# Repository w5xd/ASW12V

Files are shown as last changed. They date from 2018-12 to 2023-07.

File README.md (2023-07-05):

ASW12V

<p>
Remote controllable multi-channel AC/DC switch<br/>
ASW12V: antenna switch for 12V
</p>

My shack has a number of 12VDC controlled circuits for antennas. When
I am sitting at the operating position, they are
 controlled by rotary switches there. 
When connected to the station remotely using WriteLog, I need a way to 
control the switches from the shack PC. This device is a USB controlled
solid state multi-channel AC/DC switch. While its named "12V" the solid state
relay (SSR) outputs can
safely switch up to a maximum of 60V AC or DC, and at up to about 3A. The remainder of
this document uses "12V" to describe the power supply, even though the PCB
is more capable.

In the absence of 
control commands over its USB serial port input,
its output channels follow its input channels. USB power on the 
USB-C plug is required to power the embedded microprocessor for it to
follow its inputs.

<p>This device is controlled by ASCII command strings sent over
its USB serial port. WriteLog is not required to operate it,
but a WriteLog plugin is posted <a href='W5XD-antennas'>here</a> showing 
how to embed
antenna switching commands for this hardware
within WriteLog. The example has on-screen controls corresponding
to the antennas at W5XD. Source code is published.</p>

<p>The power and ground are optically isolated on both input and output side, and separately,
into groups of four channels. Each group of four has its own power and ground terminals.
All the input and output power and ground circuits are optically isolated
from the USB power and ground as used by the Arduino controller on the PCB.</p>
<p>

Revision 8

<p> This documentation is for Revision 8 of the ASW12V. Previous revisions of this design used 
PNP darlington output devices. This SSR design reduces the parts count, and enables both sensing
and controlling AC as well as DC circuits. See the git tag "PCB-REV05" for the documentation for the
version using the STA402 PNP darlington outputs.
</p>
Here is the 24 channel version built with wired connectors:</p>
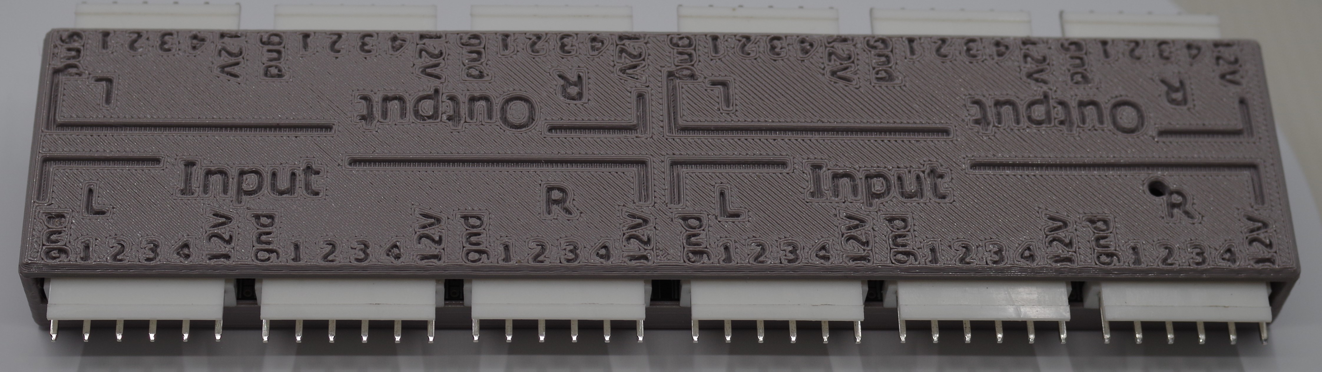
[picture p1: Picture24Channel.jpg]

The longest dimension is just less than 8 in (20cm). The short dimension is about 2.5in (6.2cm). The  
12 channel version is half as wide (4" x 2.5" or 10cm x 6.2cm). 
Here is a populated PCB before connectors are installed. the SMD components are all on the "bottom" of the PCB
and the connectors and QTpy controller (which are through-hole) are installed on the "top".
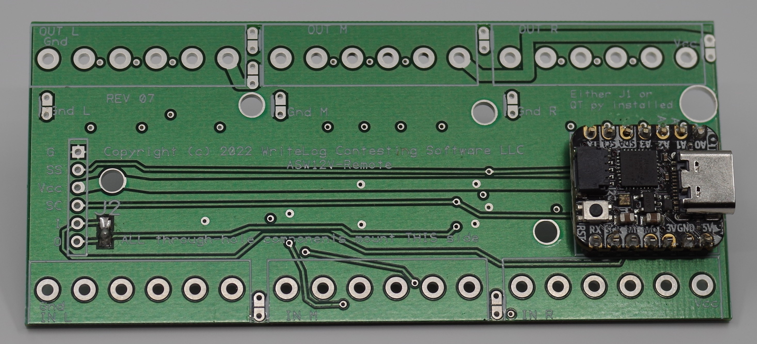
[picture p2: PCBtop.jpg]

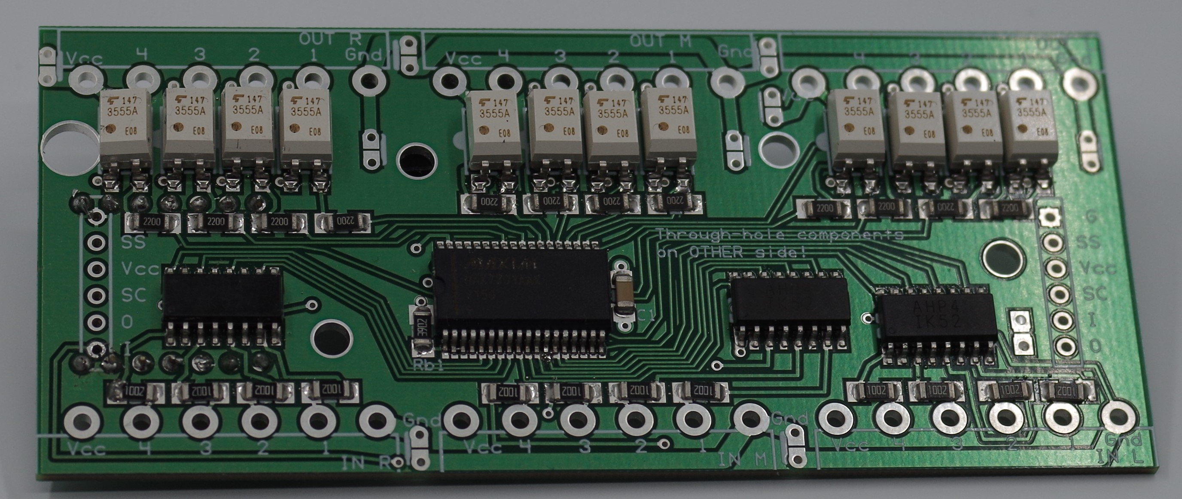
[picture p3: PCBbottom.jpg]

<p>Top and bottom are in quotes because when the SMD components are installed, they must be on  the
top of the PCB in the oven. But when the full device is assembled and in operation, the SMDs are on the bottom.</p>
<br/>
<p>Power and Ground</p>

<p>The PCB layout has three sections each with four input/output channels and with grounds and
VCC isolated to that section. In the photo above, all the G and 12V connections are, without installing any jumpers,
 isolated from each other. Solder jumpers on the PCB enable interconnects among them. See below.
 The power and ground circuit is this:
<a href='ASW12V-circuit3.pdf'>ASW12V-circuit3.pdf</a>. 
Many different power supply options are supported by jumper options on the PCB for exactly what Ground and 
VCC connections are interconnected on
the PCB. One thing that is not optional: fuse at about 3A or otherwise current limit the connection from the
 power supply to the Vcc terminal on the ASW12V. The ASW12V PCB has components too dense to service. Plan on
 replacing it if it is damaged by over current.
 
You can successfully use this device with NONE of these jumpers in place. But consider how you want to use it.
In my own case, the same 12VDC supply powers all my antenna relays, so I can safely tie all the Gnd and VCC
terminals together. Your shack may differ.

The PCB has jumpers that can internally connect:</p>
<ol>
<li>the VCC pin to the VCC on the adjacent section.
<li>the OUTPUT GND pin to the OUTPUT Gnd pin of the adjacent section.
<li>the INPUT Gnd pin to the OUTPUT Gnd pin of the section.
<li>the INPUT GND pin to the INPUT Gnd pin of the adjacent section.
 </ol>
 The positions of the jumpers are hand-outlined on this <a href='ASW12V-bottom.pdf'>bottom view of the PCB silkscreen</a>. 
 The jumpers are most easily installed (and removed) on the bottom side of the PCB. The jumpers corresponding to (1) and (2) are at the top of the picture, 
 the ones for (4), the INPUT to INPUT, are at the bottom and the ones for (3) are between.
 
 The circuit board traces are wide enough
 to suppoart a total of 3A to the VCC and GND connectors on each terminal block.
 
Construction

<p>A parts list, construction details, and a PCB layout are published <a href='construction.md'>here</a>.</p> 

Inductive Loads

The solid state relays do not have built-in protection from any inductive voltage spike that happens as
an inductive load is turned off. The PCB has 12 positions for diodes to be installed, labeled D11 up through D44.
Installing these diodes is optional. They are not needed for non inductive loads, nor for inductive loads that have
their own flyback diodes installed (e.g. the Array Solutions 6-Pak in my shack.)

Controlling the ASW12V

A USB connection to the USB-C connector is required for operation of the microcontroller. Without USB power, all outputs are
off. The sketch on the Arduino powers up
in a pass through mode. That is, the firmware transfers the INPUT
side as a pass through to the OUTPUT&mdash;a signal on an INPUT pin results in Vcc applied to corresponding OUTPUT pin on
the opposite side of the box.
<p>When plugged in to a computer, the drivers for its USB port automatically are installed (on most
 operating systems) and create a virtual serial port. An example program to write useful serial commands is published <a href='W5XD-antennas'>here on github</a>. The example
is specific to the antennas to be controlled at W5XD. It doesn't put much on the screen. as not much is required at W5XD.</p>
<p>Control the beverages, one to the RX antenna on each of two radios:</p>
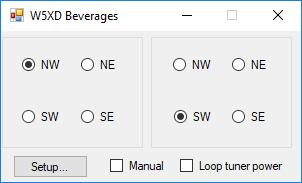
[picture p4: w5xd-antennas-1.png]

<p>Control the main transmit antenna, one of 6 to each of two radios:</p>

<p>All the buttons on the two windows above can be programmed as keyboard shortcuts in WriteLog.</p>
Enclosures

<p>This repository publishes a design for an enclosure a 24 channel device (with 2 PCBs) with connectors installed on the PCB.
 The 3D designs were done with <a href='solidedge.com'>Solid Edge</a>. 
The PCB hole pattern accommodates either the screw terminals or the connector. The
Solid Edge models are in the CAD folder. The 3D printable parts are published in the <a href="STL/">STL</a> directory. Unfamiliar with 3D design 
and printing? Don't be bashful about clicking the <a href="STL/">STL</a> link and the enclosure models. </p>

I use a <a href='http://prusa3d.com'>prusa3d</a> printer.

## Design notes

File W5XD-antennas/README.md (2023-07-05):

Antenna switch control for station W5XD

This is a .NET application for controlling the antenna switching at W5XD.
It serves as an example of both how an ASW12V might be used,
and how to split a WriteLog keyboard shortcut processor between control-site
and remote-site.

My station has these items to control:
<ul>
<li>Four beverage antennas (receive only) that each can be switched into the RX antenna port of either of two rigs. The
 rigs are called "primary" and "secondary" because my relay circuit
only routes each beverage to one rig at a time, and the primary radio always wins when both controls are switched 
    to the same direction.</li>
<li>A 12VDC supply for remote tuner (MFJ-998RT). That tuner can be commanded to find a better match by cycling its power off then back on.</li>
<li>Antennas switched with an Array Solutions <a href='https://www.arraysolutions.com/antennas-switching/sixpak-so'>SixPak</a></li>
</ul>

Also at W5XD, the operator tends to run WriteLog for his logging software (funny thing
about that.) Beverages really need to be switched from within the contest logging program
with just a keystroke. This is important when trying to pull a weak signal out of the noise at the same time as typing the CALL.
(For this particular function, its not an effective computer/user interface to
change the keyboard focus outside the logging program and then back.)

That beverage-switching problem is why this .NET application is structured to build both 
a .exe (to run standalone) and a .NET assembly.
When you open this Visual Studio solution, W5XD-antennas.sln, you build both. If you run the exe standalone 
you get control over the ASW12V,
but not from within WriteLog. Instructions for using the assembly within WriteLog are below. 

Here is a picture of how the ASW12V gets wired into the control circuits for the SixPak. (The
beverage controls are not shown here. They are similar with the exception of having only four positions
on the control switches.)
Before installing the ASW12V, the SixPak controls are wired this way:
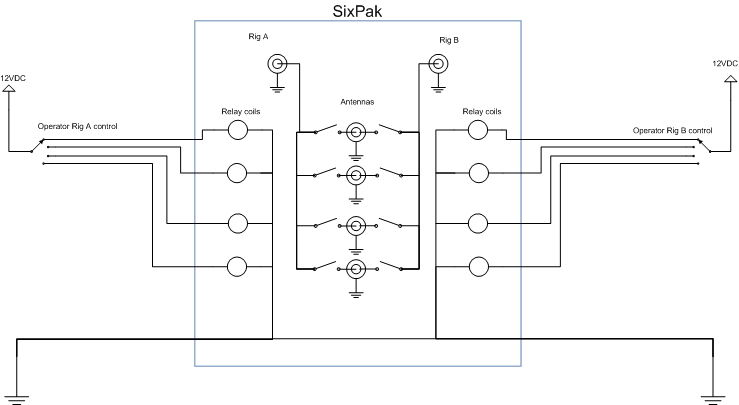
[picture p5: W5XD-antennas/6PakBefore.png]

(SixPak internal circuit here is only representative. I omit its safety latches, and 
show only four of the six channels.) Just cut the control cable between the operator position and the relay box and wire in the ASW12V:
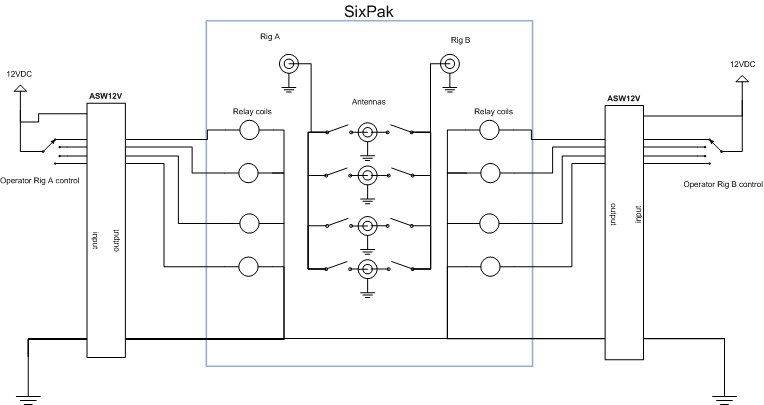
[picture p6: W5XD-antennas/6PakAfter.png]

For simplicity in the diagram I show the control cables split at
two ASW12V boxes. But in my shack, both control cables are routed through
just one ASW12V. And its the 24 channel version. The beverage
and tuner power switching are all routed to the same terminal blocks
and all controlled using one virtual COM port.
<br/>
<p>The diagram shows that power and ground are connected on the INPUT side of the ASW12V.
If your load exceeds about 1A (of the 3A maximum rating) then
wire the heavier power and ground leads to the power source on the OUTPUT side of the
ASW12V to avoid overloading the internal (and smaller) INPUT to OUTPUT power and ground jumper traces.</p>

To use within WriteLog, place a copy of the W5XD_antennas_shortcuts.dll in WriteLog's Program directory,
and make a new entry in WriteLog.ini. WriteLog can then access the beverage switching from
keyboard shortcuts. The INI entry looks like this:
<pre><code>
[ExternalShortcuts]
W5XD_antennas_shortcuts.WriteLogKeyProcessor=W5XD_antennas_shortcuts</code>
</pre>
WriteLog doesn't need the .exe file. Only the .dll need be installed in WriteLog's Program folder. To get the antenna controller on the screen assign any (or all) of its four shortcuts to keyboard keys, then invoke one.

<h3>WriteLog Remote Control</h3>
WriteLog as of its version 12.36 supports keyboard shortcut processing split across
the control-site to the remote-site. This project shows how to accomplish that
in its .NET source code. The Writelog.ini setting at the remote site is as above, but at the control site,
you need this entry instead:
<br/><code>W5XD_antennas_shortcuts.WriteLogKeyProcessorControlSite=W5XD_antennas_shortcuts</code>

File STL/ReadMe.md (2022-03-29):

STL model for 24 channel enclosure with the plug-in connectors installed (as opposed to the screw terminal connectors)

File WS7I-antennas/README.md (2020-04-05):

Antenna switch control for station WS7I

This is a .NET application for controlling the antenna switching at WS7I.
It serves as an example of both how an ASW12V might be used,
and how to split a WriteLog keyboard shortcut processor between control-site
and remote-site.

The station has one antenna switch that attaches one of these to the rig
<ul>
<li>TH7
<li>7 MHz
<li>3.5 MHz
<li>2.0 MHz
</ul>

To use within WriteLog, place a copy of the WS7I_antennas_shortcuts.dll in WriteLog's Program directory,
and make a new entry in WriteLog.ini. WriteLog can then access the beverage switching from
keyboard shortcuts. The INI entry looks like this:
<pre><code>
[ExternalShortcuts]
WS7I_antennas_shortcuts.WriteLogKeyProcessor=WS7I_antennas_shortcuts</code>
</pre>
WriteLog doesn't need the .exe file. Only the .dll need be installed in WriteLog's Program folder. To get the antenna controller on the screen assign any (or all) of its four shortcuts to keyboard keys, then invoke one.

<h3>WriteLog Remote Control</h3>
WriteLog as of its version 12.36 supports keyboard shortcut processing split across
the control-site to the remote-site. This project shows how to accomplish that
in its .NET source code. The Writelog.ini setting at the remote site is as above, but at the control site,
you need this entry instead:
<br/><code>WS7I_antennas_shortcuts.WriteLogKeyProcessorControlSite=WS7I_antennas_shortcuts</code>

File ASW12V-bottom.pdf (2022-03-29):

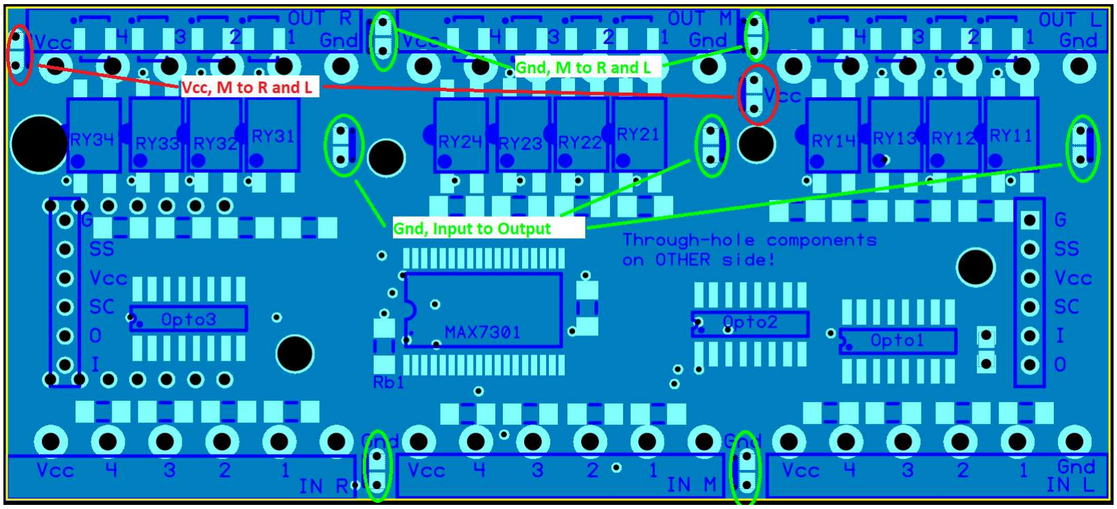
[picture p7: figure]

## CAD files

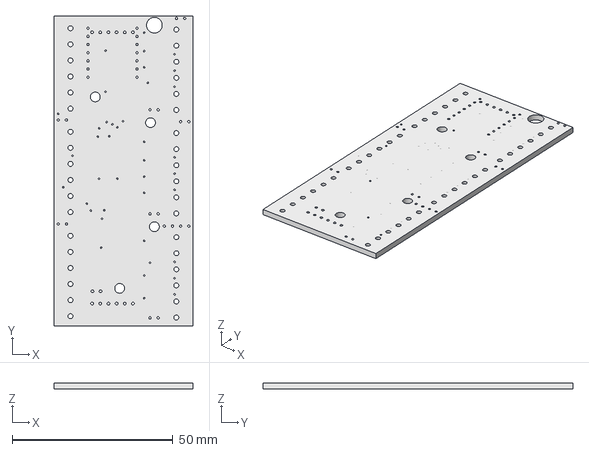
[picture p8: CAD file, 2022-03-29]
SolidEdge/pcb-qtpy.step
43.2 x 96.5 x 1.78 mm

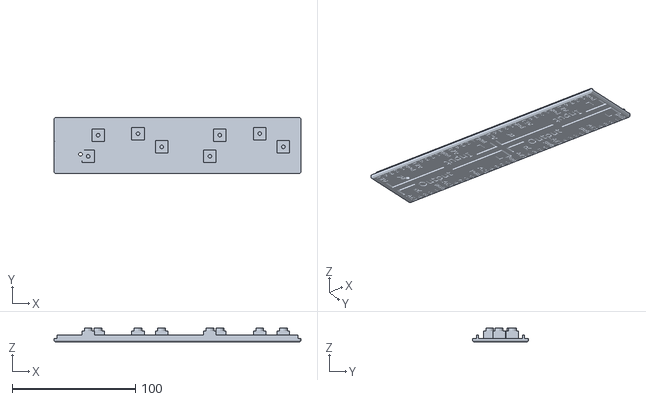
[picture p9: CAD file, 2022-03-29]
SolidEdge/QTpy/enc24-top.stl
200.4 x 45.8 x 11.1

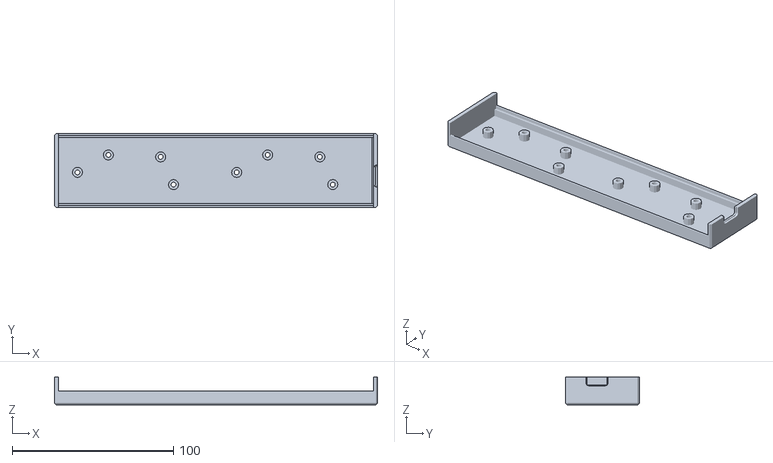
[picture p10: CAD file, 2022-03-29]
STL/enc24-bottom.stl
200.4 x 45.8 x 17.2

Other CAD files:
STL/enc24-top.stl

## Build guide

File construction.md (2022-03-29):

ASW12V Construction
<h3>Parts lists</h3>
The parts of a 12-channel, single-PCB device can all&mdash;except the PCB and enclosure&mdash; be obtained at digikey:
<a href="partslist.pdf">partslist.pdf</a>.
Or here is a link to the equivalent digikey shared shopping cart:
<a target="_blank" href="https://www.digikey.com/short/tr1t8r3d">https://www.digikey.com/short/tr1t8r3d</a>.

<p>The digikey references above do <b>not</b> include the necessary input/output screw terminals or connectors. The PCB design accommodates 
either of these connector configurations:</p>
<ul>
<li><a target="_blank" href='https://www.digikey.com/short/z8zprc'>Phoenix Contact 1935200 </a>. (screw terminals)<br/>
OR
<li><a target="_blank" href='https://www.digikey.com/short/z8zprj'>TE Connectivity AMP Connectors part 1744048-6</a>. (male pins on plug.)
This plug mates with these parts:
<ul>
<li><a target="_blank" href='https://www.digikey.com/short/z8zprb'>mating housing</a>
<li><a target="_blank" href='https://www.digikey.com/short/z8zprd'>crimp pins</a>
</ul>
</ul>

<p>The parts lists above also do <b>not</b> include the board-to-board connectors you'll need to 
interconnect the two PCBs if you build the 24 channel version:</p>
<ul>
<li><a target="_blank" href='https://www.digikey.com/short/z8prdt'>Right angle connection header, male</a>. </li>
<li><a target="_blank" href='https://www.digikey.com/short/zp42fr'>Right angle connection header, female</a>. </li>
<li>Double all the quantities in the parts list above.</li>
</ul>

If you're going to build several of these in a batch, here is a handy <a href='https://www.digikey.com/short/zp4253'>part</a>. 
It can be used with a jig (which you'll have to design and build) to jumper any Arduino (of any size)
 to test a partially 
populated PCB. See the testing instructions <a href='#TestJig'>below</a>.

The printed circuit board is a four layer design. You must have them built.
It was designed with <a target="_blank" href="http://expresspcb.com">expresspcb</a> and the
file is ASW12V.rrb. 
<ol>
<li>This repository maintains only the most recent PCB revision's documentation in the master branch. Look for tags to find documentation of older revisions.</li>
<li>Revision 8 uses Solid State Relay outputs, the QTpy Arduino device, and the MAX7301 i/o extender. Its the
smallest form factor of all the revisions.</li>
<li>Revision 6 accommodates the pinout of the more readily available STA402 10-pin SIP PNP darlington, and 
adds 2 Amp SMD size <code>1206</code> flywheel diodes to accommodate inductive loads (which includes, for example, a relay coil!) The 
SMA4021 part for earlier PCBs has built-in flywheel diodes.
<li>Revision 5 is identical to Revision 6, but its gerber file.top has been hand edited to remove a stray trace.
<li>Revision 4 adds pads for SMD <code>1206</code> size resistors while the through-hole positions remain an option. 
	Install one or the other. </li>
	<li>Revision 4 and earlier accommodate the SMA4021 12-pin SIP Darlington PNP with built-in flywheel diodes. </li>
<li>Revision 3 and later of the PCB is limited to 3A among its outputs.
Earlier revisions have lower current limits. Revision 3 and later of the PCB accommodates either of the above interconnects. </li>
</ol>
 
Program the Arduino QTpy with the sketch published in <a href="sketch//ASW12V">sketch/ASW12V/</a>. 

<h3>Construction Recommendations</h3>
    
Install <i>only</i> the SMD parts and stop to test:
<ol type="a">
    <li>You will need reflow solder oven.</li>
   <li>Place and bake all the SMD parts.</li>
</ol>
There is more than one way to test for solder bridges and/or pins that missed soldering. Choose a way to test
and verify the SMD components are working before soldering the Input and Output connectors. Its a lot harder to work
with the board with those connectors in place.

Possible hardware configurations for testing

All the jumpers on the PCB have through holes for a wire jumper, and also have solder pads on both the top
and the bottom so you can bridge a blob of solder across the jumper. This pad configuration is on all of them: 
the I to O jumper at J2, the GND
jumpers and both of the Vcc jumpers.
<ol>
<li>Install the QTpy on the PCB (<b>notice it goes on the opposite side of the board from the SMD parts!</b>)<br/>
OR</li>

<li>Install male headers on your QTpy and then use
<ol type="a">
    <li> 6 jumpers to temporarily wire it to the PCB. I used these jumpers from 
<a href='http://www.sparkfun.com/products/10898'>sparkfun</a>.</li>
    <li>If this test is for a board that will have the QTpy controller, then 
    you may install a sacrificial header now at J1.
A vertical header (straight pins) will work, but if you don't know where you're going to
    install this board, then install a right angle header as if it will not be the first board (i.e. one without
a QT py). If it ever is to become the first board,
    you'll have to cut all the pins off the header for mechanical clearance. But by then they'll not be needed.</li>
    <li>
        jumper the I pin to the O pin at J2. A jumper is required for the last board in the chain
both for testing and for normal operation. A right angle female header
	is required at J2 for any board that has another beyond it. 
In either case, for initial test, install this jumper. 
    </li>
    <li>The jumper list from J1 to the Arduino:
    <ol type='1'> 
        <li>SS to the slave select pin (named M7301_SELECT) in the Arduino sketch</li>
        <li>G to either pin GND</li>
        <li>vcc to Vcc. (The MAX7301 is OK up to 5V, but will be run at 3.3 V once the QTpy is installed)</li>
        <li>O to the SPI MISO pin</li>
        <li>I to the SPI MOSI pin</li>
        <li>SC to the SPI SCK pin</li>
    </ol>
    </li>
</ol>
</li>
<ol>

<p id='TestJig'>Or if you're building more than one of these at a time, A test jig might come in handy. 
There is no need to
commit to a particular set of headers because the spring loaded connector holds well enough to test with 
jumper leads per these
photographs. 
</p>
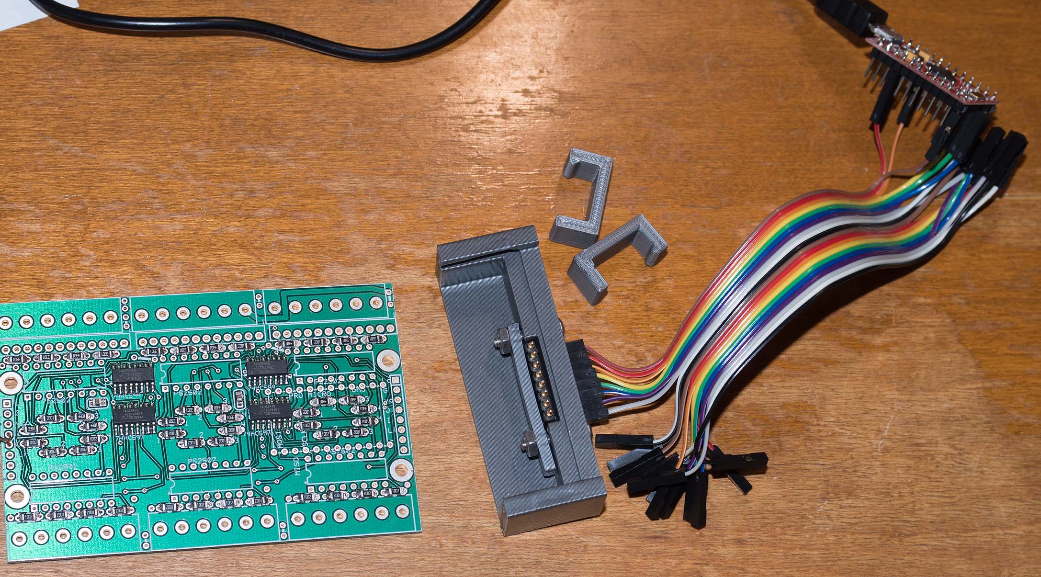
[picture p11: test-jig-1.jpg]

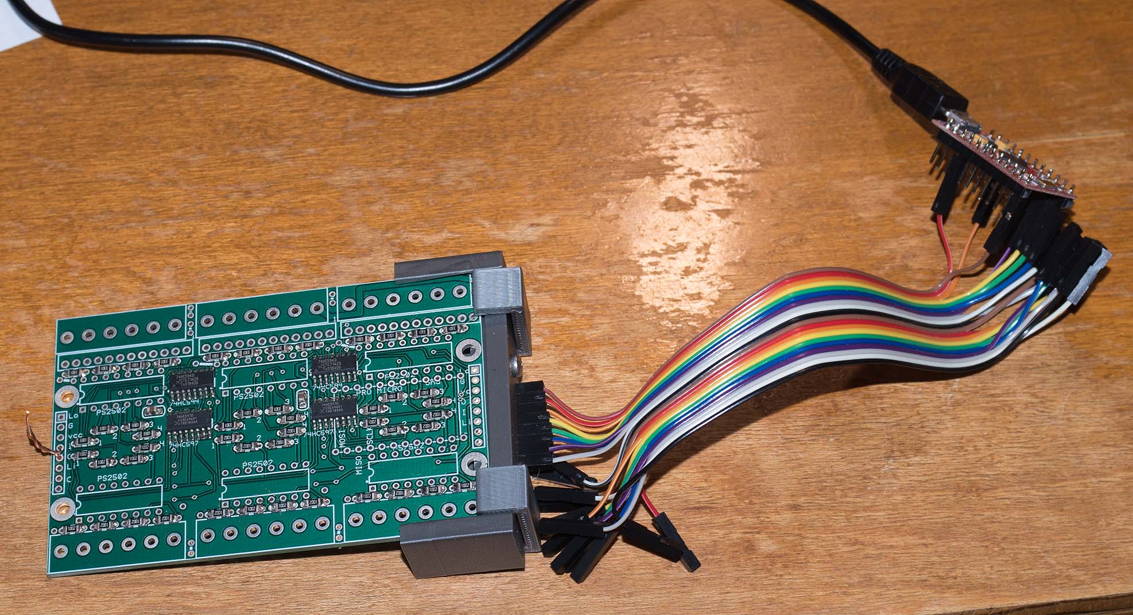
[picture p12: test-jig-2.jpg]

<p>The photos above are for REV05 of the PCB. I did not design jigs for the REV08 PCB
because its easy enough to solder the QTpy directly to the board.</p>

<h3>Shift Register Digital Test</h3>
You need a serial port terminal program connected to
the Arduino&#8217;s serial port for the following tests. I recommend
<a href="https://www.chiark.greenend.org.uk/~sgtatham/putty/latest.html">putty.exe</a>.
Click its "Serial" button in its upper right to put it in serial port terminal mode. You will also need a DVM to 
accomplish these tests. The tests are easier to do if you buid the sketch with 
<pre><code>#define DBG_PRINT 1</code>
</pre>
<ol>
    <li>
        Test that the
        <code>d</code> command correctly tells you there is one board in the daisy chain.
    </li>
    <li>
        Test the
        <code>I</code> command (which is only available with DBG_PRINT set). 
    </li>
</ol>
<p>Do <b><i>not</i></b> install any more parts until the above two tests succeed. </p>

<h3>Digital Input Test</h3>

Type the <code>i</code> command while using a test lead to, one at a time,
short these adjacent pins on each of the <i>input</i> optoisolators (also one at a time):
<ul>
    <li>16 to 15 (prints out a "1" in the corresponding <code>i</code> command)</li>
    <li>14 to 13 (prints out a "2"...)</li>
    <li>12 to 11 (prints out a "4"...)</li>
    <li>10 to 9 (prints out "8").</li>
</ul>
There are 12 input signals to verify. Do <b><i>not</i></b> install any more parts until this test succeeds.
    
<h3>Digital Output Test</h3>

Use the <code>C</code> command to clear the internal test state, and then repeatedly
use the <code>t</code> command to assert each channel in the daisy change, right most to left
with the board top-up and the silk screen lettering right-side-up.
The HIGH output is Vcc for the Arduino you are using: either 3.3V or 5.0 V.

Add the connectors <b><i>only</i></b> after you verify each of the outputs.

<h3>12V output section test</h3>
The SSR outputs respond to a DVM ohmmeter set to beep on low resistance. Verify that
ONLY the one SSR output shows continuity between its output pin and its Vcc pin.
<ul>
<li><code>m 1 L0F</code> <i>turns OFF all the L outputs</i>
<li><code>m 1 L1F</code> <i>turns ON only the L 1 output</i>
<li><code>m 1 L2F</code> <i>turns ON only the L 2 output</i>
<li><code>m 1 L4F</code> <i>turns ON only the L 3 output</i>
<li><code>m 1 L8F</code> <i>turns ON only the L 4 output</i>
</ul>
<p>For the <code>L</code>, substitute <code>M</code> when 
testing the middle section and <code>R</code> when testing the right section.</p>

<p>The GND and VCC jumpers on the PCB, if needed, are most easily installed on the <a href='ASW12V-bottom.pdf'>bottom</a>. There is a discussion about why you would or would not install the jumpers in the main <a href='README.md'>README</a>.</p>

<h3>Enclosure</h3>

The enclosure is documented in the <a href="CAD/">CAD</a> and <a href='STL/'>STL</a> folders.
The mounting posts on the enclosure top have channels that fit #4 machine nuts. Square nuts are easier to
place, but hex nuts work as well. In either case, clean out the 3D printing debris before
pushing a nut in the channel.  And put a small piece of tape over the opening after the nut
is placed because gravity is going to try to remove it while you do the remainder of the assembly.  

Quantity 4 by 3/4 (or 5/8) inch machine screws are needed per section to fasten the top to the bottom.

The mounting screw holes in the enclosure bottom can be cleared of print debris by pushing a
#4 machine screw through from the inside toward the outside.

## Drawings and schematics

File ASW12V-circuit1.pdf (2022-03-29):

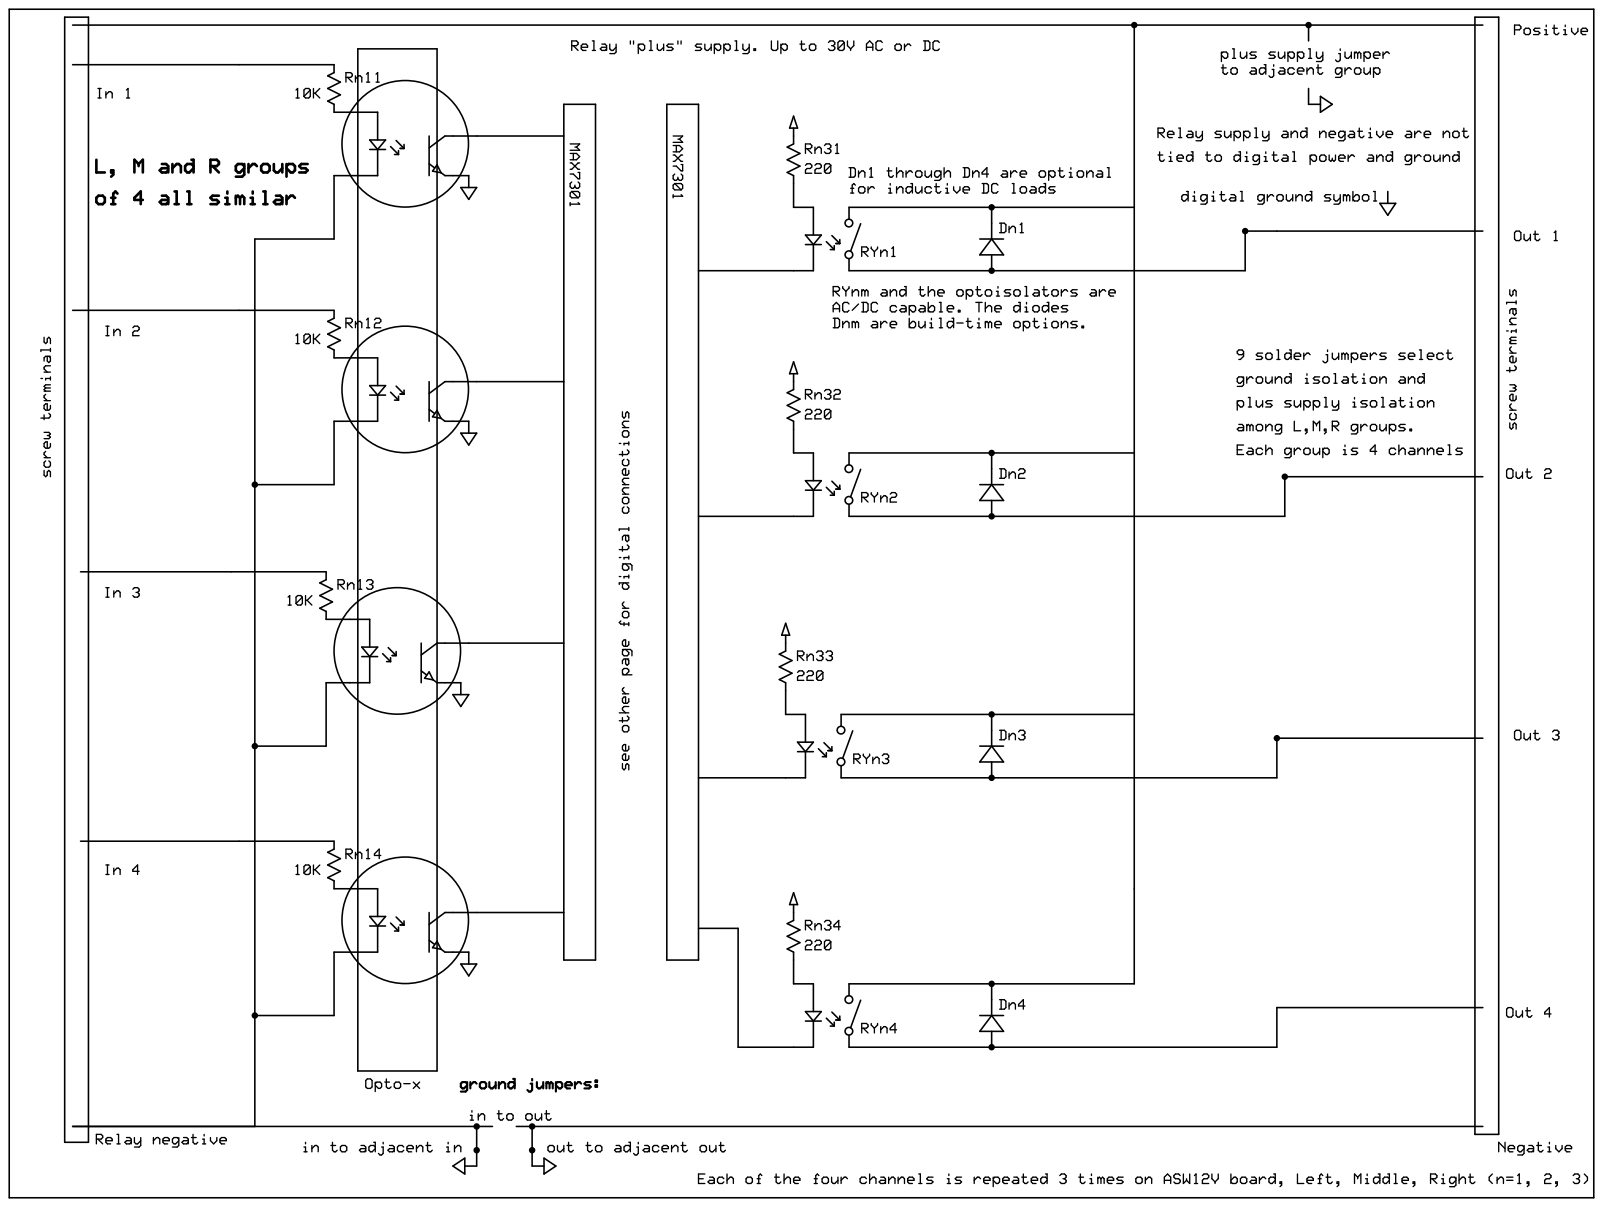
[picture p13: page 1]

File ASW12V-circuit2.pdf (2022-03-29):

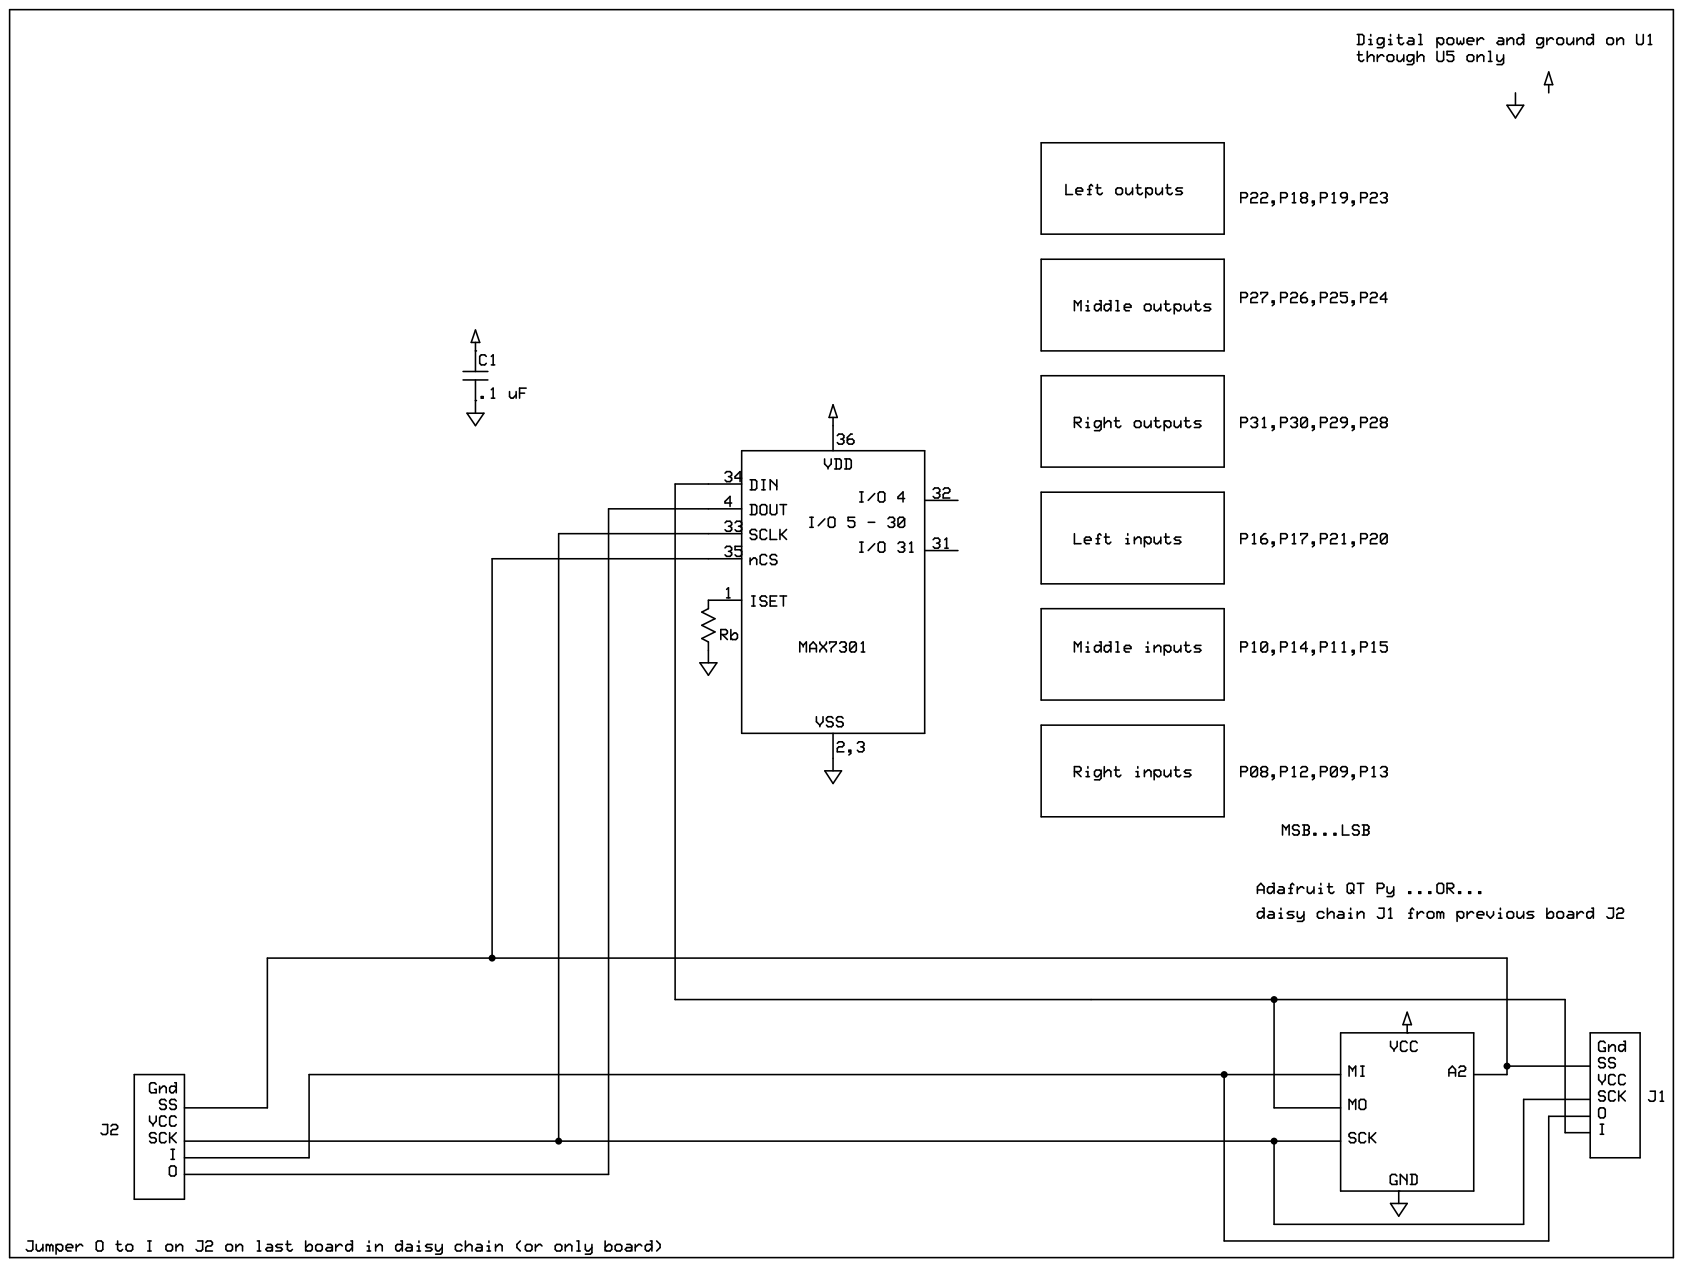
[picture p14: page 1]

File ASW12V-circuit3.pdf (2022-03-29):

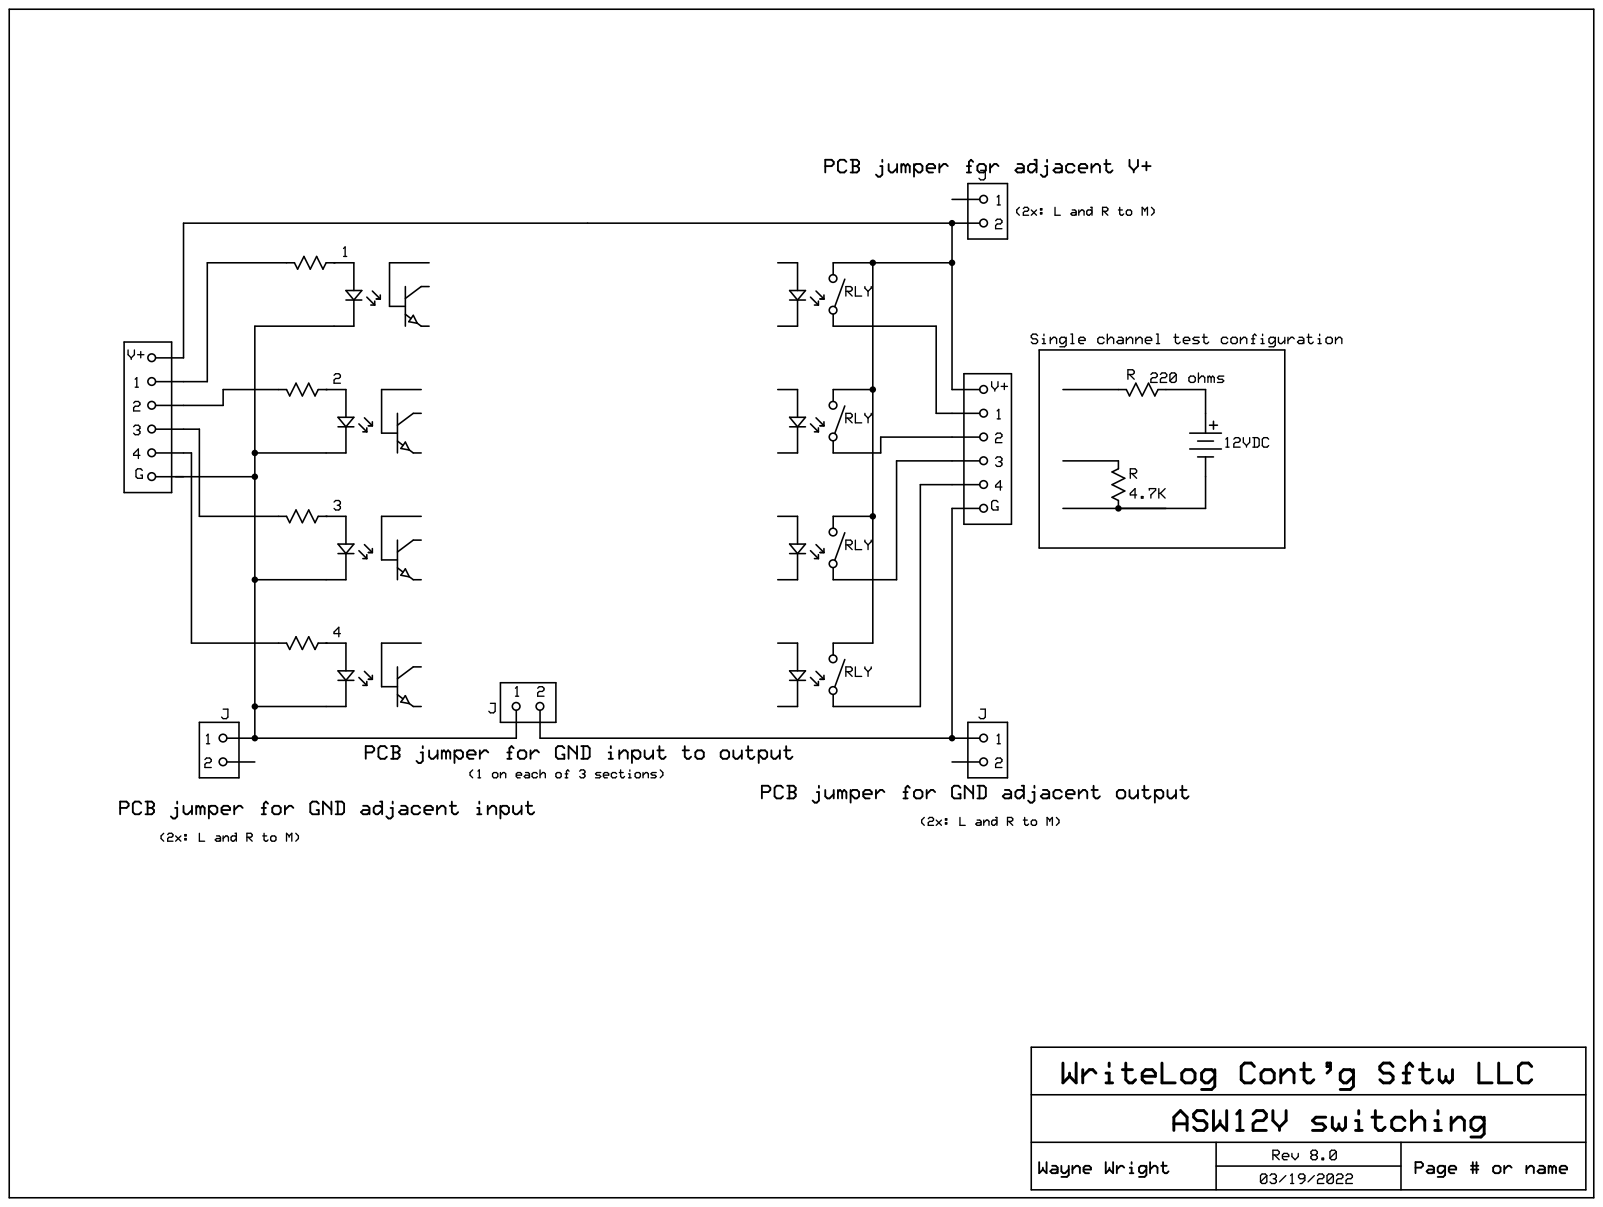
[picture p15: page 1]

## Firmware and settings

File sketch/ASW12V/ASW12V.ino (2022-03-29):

#include <SPI.h>
#include <Adafruit_NeoPixel.h>
#define DIM(x) (sizeof(x) / sizeof((x)[0]))
#define DBG_PRINT 0
#define SUPPORT_NEOPIXEL_STATUS 1 // turn this off to test on an arduino with no NeoPixel

/* Arduino sketch for the ASW12V remote control switch box
** The hardware is an array of input screw terminals and 
** an array of output screw terminals of the same size.
** The "12V" in the name is only because 12VDC is typically
** used in ham antenna control boxes. This circuit can handle
** up to 60V and either AC or DC.
**
** The architecture is to be able to insert this device
** in a low voltage switching circuit such that 
** manual switching at our inputs controls the 
** devices at our outputs by asserting supply voltage on 
** those outputs in various combinations. The circuit 
** isolates the controlled supply and ground from our Arduino
** power, which is on USB power. 
** The TLP355A solid state relay (SSR) can switch up 60V AC or DC
** The circuit board traces on the OUTPUT side of the PCB
** are capable of handling 3A. The INPUT side has 
** narrower traces.
**
** All the input sensing channels and all the output control channels
** are on a single MAX7301 Port expander. It has a 28 channel capacity,
** of which we need 12 inputs and 12 outputs. The MAX7301 numbers its
** channels starting at P4 up through P31. This design leaves the four
** lowest unused, and uses P8 through P31.
**
** At code startup, we assume we're operating stand alone, which
** means copying our inputs 
** to our outputs. "We" means this sketch on the Arduino.
** It uses only 3 SPI pins and a M7301_SELECT pin. VCC and ground are the remaining
** connections. The Adafruit QT Py device has all these pins,
** is tiny, and has a USB-C connector with 500mV of 3.3VDC available
** to power the control circuits. 
**
** The board is designed for daisy chaining. That means 
** we might have another MAX7301 on a second circuit
** board cabled to our J2 and their J1. The daisy chaining
** can continue to more boards.
** This firmware needs to know how many boards
** are out there on the daisy chain. It calculates that by insisting:
** a) that the final board on the daisy chain (even if
** we're the only board) has its J2 I/O pins jumpered 
** together. That allows us to shift data out and detect
** when it comes back.
** b) in order to put a limit on how much work we must do
** to detect the length of the daisy chain, that
** number is limited to 8 boards (which totals 96 channels.)
**
** Once we detect the length of the daisy chain, 
** our loop() copies the input registers to
** the output registers. 
**
** The LED in each SSR requires about
** 10mA to turn on. That means a limit of at most 50 channels ON at one time.
**
** loop() also monitors the serial input for commands.
** One set of commands is designed for self test.
**
*/

namespace {
    const int M7301_SELECT = A2; // the PCB wires the QT PY pin A2 to the MAX7301 select
    const int MAX_BOARDS_DAISY_CHAINED = 8;
    const uint8_t WRITE_MAX7301_P08 = 0x48u;

    const uint8_t WRITE_MAX7301_P16 = 0x50u;
    const uint8_t WRITE_MAX7301_P24 = 0x58u;
    const uint8_t READ_MAX7301_MASK = 0x80u;
    const uint8_t READ_MAX7301_P08 = WRITE_MAX7301_P08 | READ_MAX7301_MASK;
    const uint8_t READ_MAX7301_P16 = WRITE_MAX7301_P16 | READ_MAX7301_MASK;
    const uint8_t PORT_CONFIG_MAX7301_P04 = 0x9u;
    const uint8_t PORT_CONFIG_MAX7301_P08 = 0xAu;
    const uint8_t PORT_CONFIG_MAX7301_P12 = 0xBu;
    const uint8_t PORT_CONFIG_MAX7301_P16 = 0xCu;
    const uint8_t PORT_CONFIG_MAX7301_P20 = 0xDu;
    const uint8_t PORT_CONFIG_MAX7301_P24 = 0xEu;
    const uint8_t PORT_CONFIG_MAX7301_P28 = 0xFu;
    const uint8_t CONFIG_MAX7301 = 0x4u;
    const uint8_t MAX7301_NOOP = 0;
    const uint8_t MAX7301_DUMMY = 0;
    const uint8_t CONFIG_NORMAL = 1u;

    const uint8_t PORT_P18_P19_OUTPUT = 0b01010000u;
    const uint8_t PORT_P22_P24_OUTPUT = PORT_P18_P19_OUTPUT;

    const uint8_t PortSetup[][2] =
    {
        {PORT_CONFIG_MAX7301_P08, 0xffu},
        {PORT_CONFIG_MAX7301_P12, 0xffu},
        {PORT_CONFIG_MAX7301_P16, 0xfu | PORT_P18_P19_OUTPUT},
        {PORT_CONFIG_MAX7301_P20, 0xfu | PORT_P22_P24_OUTPUT},
        {PORT_CONFIG_MAX7301_P24, 0x55u},
        {PORT_CONFIG_MAX7301_P28, 0x55u},
        {WRITE_MAX7301_P16, 0xff},
        {WRITE_MAX7301_P24, 0xff},
        {CONFIG_MAX7301, CONFIG_NORMAL},
    };
}

struct ShiftRegister_t {
    uint8_t LeftRegister; // high 4 bits are left register.
    uint8_t RightAndMiddleRegister; // low 4 are Middle, high 4 are Right
    ShiftRegister_t() : LeftRegister(0), RightAndMiddleRegister(0){}
    void init() { LeftRegister = RightAndMiddleRegister = 0;}
    // the channels are numbered 0 through 3 which are,
    // respectively, numbered 1 through 4 on the PCB silkscreen
    void setLeftBits(uint8_t channel, uint8_t mask) // both range of 0 to f 
    {   
        mask &= 0xf; // only 4 bits allowed, the least ones.
        LeftRegister &= ~mask;
        LeftRegister |= channel & mask;
    }
    void setMiddleBits(uint8_t channel, uint8_t mask)
    {
        mask &= 0xf;
        RightAndMiddleRegister &= ~mask;
        RightAndMiddleRegister |= channel & mask;
    }
    void setRightBits(uint8_t v, uint8_t mask)
    {
        mask <<= 4;
        mask &= 0xf0;
        RightAndMiddleRegister &= ~mask;
        RightAndMiddleRegister |= (v<<4) & mask;
    }

    uint8_t rawMRout()
    {   // translate RightAndMiddleRegister to WRITE_MAX7301_P24
#if 0 // if we bit diddle
        static const int P24_BIT = 0;
        static const int P25_BIT = 1;
        static const int P26_BIT = 2;
        static const int P27_BIT = 3;
        static const int P28_BIT = 4;
        static const int P29_BIT = 5;
        static const int P30_BIT = 6;
        static const int P31_BIT = 7;
        uint8_t ret = 0xff;
        // middle bits
        if (RightAndMiddleRegister & 1)
            ret &= ~(1 << P24_BIT);
        if (RightAndMiddleRegister & 2)
            ret &= ~(1 << P25_BIT);
        if (RightAndMiddleRegister & 4)
            ret &= ~(1 << P26_BIT);
        if (RightAndMiddleRegister & 8)
            ret &= ~(1 << P27_BIT);
        // right bits
        if (RightAndMiddleRegister & 0x10u)
            ret &= ~(1 << P28_BIT);
        if (RightAndMiddleRegister & 0x20u)
            ret &= ~(1 << P29_BIT);
        if (RightAndMiddleRegister & 0x40u)
            ret &= ~(1 << P30_BIT);
        if (RightAndMiddleRegister & 0x80u)
            ret &= ~(1 << P31_BIT);
        return ret;
#else // but the PCB layout arranges for these outputs to align with the MAX7301 pin layout
        return ~RightAndMiddleRegister;
#endif
    }

    uint8_t rawLout()
    {   // translate LeftRegister to WRITE_MAX7301_P16
        static const int P18_BIT = 2;
        static const int P19_BIT = 3;
        static const int P22_BIT = 6;
        static const int P23_BIT = 7;
        uint8_t ret = 0xff;
        if (LeftRegister & 1)
            ret &= ~(1 << P23_BIT);
        if (LeftRegister & 2)
            ret &= ~(1 << P19_BIT);
        if (LeftRegister & 4)
            ret &= ~(1 << P18_BIT);
        if (LeftRegister & 8)
            ret &= ~(1 << P22_BIT);
        return ret;
    }
};

static const int NUM_CHANNELS_PER_SECTION=4;
struct ShiftRegisterWithTimer_t : public ShiftRegister_t
{
    static const int DELAY_DETECTING_ZERO_MSEC; // to support AC input
    void rawMRin(uint8_t v, bool allowZeroing)
    {   // translate the results of READ_MAX7301_P08 to RightAndMiddleRegister 
        static const int P08_BIT = 0;
        static const int P09_BIT = 1;
        static const int P10_BIT = 2;
        static const int P11_BIT = 3;
        static const int P12_BIT = 4;
        static const int P13_BIT = 5;
        static const int P14_BIT = 6;
        static const int P15_BIT = 7;

        static const int M_BIT_NUMBER[NUM_CHANNELS_PER_SECTION] = {
            P15_BIT, P11_BIT, P14_BIT, P10_BIT
        };
        static const int R_BIT_NUMBER[NUM_CHANNELS_PER_SECTION] = {
            P13_BIT, P09_BIT, P12_BIT, P08_BIT
        };

        auto now = millis();
        int i = 0;
        if (!allowZeroing)
        {   // extend the debounce timers if we've been held off
            for (i = 0; i < NUM_CHANNELS_PER_SECTION; i++)
            {
                SinceReadZeroMsecM[i] = now;
                SinceReadZeroMsecR[i] = now;
            }
        }

        uint8_t tempRM = 0;
        // translate v to tempRM
        // invert cuz input v is active low, but tempM/R are active high
        for (i = 0; i < NUM_CHANNELS_PER_SECTION; i++)
        {
            const uint8_t maskM = 1 << i;
            if (0 == (v & (1 << M_BIT_NUMBER[i])))
            {   // bit is active in input
                tempRM |= maskM;
                SinceReadZeroMsecM[i] = now;
            }
            else if (static_cast<unsigned long>(now - SinceReadZeroMsecM[i]) < DELAY_DETECTING_ZERO_MSEC)
                tempRM |= maskM & RightAndMiddleRegister; // keep bit on if RightAndMiddleRegister was on

            const uint8_t maskR = 1 << (i + 4);
            if (0 == (v & (1 << R_BIT_NUMBER[i])))
            {   // bit is active in input
                tempRM |= maskR;
                SinceReadZeroMsecR[i] = now;
            }
            else if (static_cast<unsigned long>(now - SinceReadZeroMsecR[i]) < DELAY_DETECTING_ZERO_MSEC)
                tempRM |= maskR & RightAndMiddleRegister; // keep bit on if RightAndMiddleRegister was on
        }

        RightAndMiddleRegister = tempRM;
    }

    void rawLin(uint8_t v, bool allowZeros)
    {   // translate READ_MAX7301_P16 to L
        static const int P16_BIT = 0;
        static const int P17_BIT = 1;
        static const int P20_BIT = 4;
        static const int P21_BIT = 5;
        static const int L_BIT_NUMBER[NUM_CHANNELS_PER_SECTION] = {
            P20_BIT,  P21_BIT, P17_BIT, P16_BIT
        };

        auto now = millis();
        int i = 0;
        if (!allowZeros)
        {   // extend debounce timers
            for (i = 0; i < NUM_CHANNELS_PER_SECTION; i++)
                SinceReadZeroMsecL[i] = now;
        }

        uint8_t tempL = 0;
        // translate v to tempL
        // invert cuz input v is active low, but tempL is active high
        for (i = 0; i < NUM_CHANNELS_PER_SECTION; i++)
        {
            const uint8_t mask = 1 << i;
            if (0 == (v & (1 << L_BIT_NUMBER[i])))
            {   // bit is active in input
                tempL |= mask;
                SinceReadZeroMsecL[i] = now;
            }
            else if (static_cast<unsigned long>(now - SinceReadZeroMsecL[i]) < DELAY_DETECTING_ZERO_MSEC)
                tempL |= mask & LeftRegister; // keep bit on if LeftRegister was on
        }

        LeftRegister = tempL;
        LeftRegister |= 0xc0; // for compatibility with older PCB that always reads those two highest bits zero
    }
protected:
    unsigned long SinceReadZeroMsecL[NUM_CHANNELS_PER_SECTION];
    unsigned long SinceReadZeroMsecM[NUM_CHANNELS_PER_SECTION];
    unsigned long SinceReadZeroMsecR[NUM_CHANNELS_PER_SECTION];
};
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
void loop()
{
    static enum {PARSE_DEFAULT, PARSE_MASK} ParseState = PARSE_DEFAULT;
    if (Serial.available() > 0)
    {
        int incoming = Serial.read();
        if (ParseState == PARSE_DEFAULT)
        {
            // commands are a single character
            if ((char)incoming == (char)'\r')
                Serial.println("ASW12V controller"); // tell user we're here...
            else if ((char)incoming == (char)'d')
            {   // print daisy chain length
                Serial.print("Daisy chain length = ");
                Serial.println(DaisyChainLength);
                OperatingMode = MODE_DEFAULT;
            }
            else if ((char)incoming == (char)'c')
            {   // clear all control masks
                for (int i = 0; i < MAX_BOARDS_DAISY_CHAINED; i++)
                {
                    MaskForceOn[i].init();
                    MaskForceOff[i].init();
                }
                Serial.println("All control masks cleared");
                channelToWrite = 0;
                OperatingMode = MODE_DEFAULT;
            }
            else if ((char)incoming == (char)'i')
            {   // print current inputs
                Serial.print("Read:");
                for (int i = 0; i < DaisyChainLength; i++)
                {
                    unsigned char receivedRM = ShiftRegisters[i].RightAndMiddleRegister;
                    unsigned char receivedL = ShiftRegisters[i].LeftRegister;
                    Serial.print(" ");
                    Serial.print((int)receivedL, HEX);
                    Serial.print(" ");
                    if (receivedRM < 16)
                        Serial.print("0");
                    Serial.print((int)receivedRM, HEX);
                }
                Serial.println();
            }
            else if ((char)incoming == (char)'o')
            {   // print current outputs
                printOutOnce = true;
            }
            else if ((char)incoming == (char)'t')
            {   // shift a single ONE across all the outputs for each "t" press
                OperatingMode = MODE_MANUAL;
                if (DaisyChainLength > 0)
                {
                    //channelToWrite < 12 is right-most board
                    // up to 24 is second, etc.
                    if ((unsigned)channelToWrite >= 12 * (unsigned)DaisyChainLength)
                        channelToWrite = 0;
                    Serial.print("Right-to-Left channel ");
                    Serial.print(1 + channelToWrite);
                    Serial.println(" is ON. all others OFF.");
                    // channel numbers for test documentation start at right and work to left.
                    // but we have to write shift registers at left and work to right
                    // so transpose the channel number to that higher is right
                    unsigned char channelToWriteInThisBoard = (12 * DaisyChainLength) - 1 - (unsigned)channelToWrite;
                    // and count down during shifting by boards, 
                    for (int i = 0; i < DaisyChainLength; i++)
                    {
                        unsigned char outputRM = 0; // 8 bits 
                        unsigned char outputL = 0;   // 4 bits are output
                        if (channelToWriteInThisBoard < 12)
                        {
                            uint16_t mask = 1u << (unsigned)channelToWriteInThisBoard;
                            static const unsigned char boardMask[8] =
                            {
                                0x80, 0x40, 0x20, 0x10, 8, 4, 2, 1,
                            };
                            if (channelToWriteInThisBoard < 4)
                                outputL = boardMask[7 - channelToWriteInThisBoard];
                            else
                                outputRM = boardMask[11 - channelToWriteInThisBoard];
                            AsOutput[i].LeftRegister = outputL;
                            AsOutput[i].RightAndMiddleRegister = outputRM;
                        }
                        channelToWriteInThisBoard -= 12;
                    }
                    writeOutputs(AsOutput);
                    channelToWrite += 1;
                }
            }
            else if ((char)incoming == (char)'m')
            {
                ParseState = PARSE_MASK;
                OperatingMode = MODE_OPERATE;
            }
            else if ((char)incoming == (char)'n') 
            {   
                Serial.print("numNotOKtoZero="); Serial.println(numNotOkToZero);
            }
#if DBG_PRINT
            else if ((char)incoming == (char)'C')
            {
                Configure7301();
            }
            else if ((char)incoming == (char)'I')
            {
                readInputs(ShiftRegisters);
            }
            else if ((char)incoming == (char)'M')
                processCopyMode();
#endif
        } else if (ParseState == PARSE_MASK)
        {
            // Mask command syntax:
            // m <board-number> <L|M|R><value><mask> [repeat]
            //   The <L|M|R><value><mask> can be repeated multiple times on the same line                
            // where:
            //   m is the character m
            //   <board-number> is a single digit signifying which daisy-chained board in the range 1-9
            //   <L|M|R> is one of the characters L,M or R
            //   value is a single hex digit 0-9 a-f or A-F
            //   mask is a single hex digit 0-9 a-f or A-F
            // The spaces after m and n are required. There are no other spaces
            static bool MaskInitialized;
            static int WhichBoard=-1;
            static ShiftRegister_t MaskOn;
            static ShiftRegister_t MaskOff;
            static const char *ErrorMessage;

            static uint8_t cmdValue;
            static enum {MASK_IS_L, MASK_IS_M, MASK_IS_R} MaskOnWhat;

            static enum {MASK_PARSE_INIT, MASK_PARSE_N, 
                MASK_PARSE_LMR_W, 
                MASK_PARSE_LMR, MASK_PARSE_V, MASK_PARSE_MASK,
                MASK_PARSE_BAD} MaskParseState;

            if (!MaskInitialized)
            {
                MaskInitialized = true;
                WhichBoard = -1;
                MaskOn.init();
                MaskOff.init();
                MaskParseState = MASK_PARSE_INIT;
                ErrorMessage = 0;
            }

            if ((char)incoming == (char)'\r')
            {
                // The m command...
                // ... sets up runtime masks that, at loop() time, force a given
		// output either on or off regardless of input. By default, 
		// each output is driven by its corresponding input.
                static const char usage[] = "usage: m <board-number> <L|M|R><value><mask> [repeat]";
                if (MaskParseState == MASK_PARSE_BAD)
                {
                    if (!ErrorMessage)
                        ErrorMessage = "Invalid mask input";
                    Serial.println(ErrorMessage);
                    Serial.println(usage);
                }
                else if (WhichBoard >= 0)
                {
                    MaskForceOn[WhichBoard] = MaskOn;
                    MaskForceOff[WhichBoard] = MaskOff;
                    Serial.print("Setting board ");
                    Serial.print(WhichBoard+1);
                    Serial.print(" ON ");
                    Serial.print((int)MaskOn.LeftRegister, HEX);
                    Serial.print(" ");
                    Serial.print((int)MaskOn.RightAndMiddleRegister, HEX);
                    Serial.print(" OFF ");
                    Serial.print((int)MaskOff.LeftRegister, HEX);
                    Serial.print(" ");
                    Serial.println((int)MaskOff.RightAndMiddleRegister, HEX);
                }
                else
                    Serial.println(usage);
                MaskInitialized = false;
                ParseState = PARSE_DEFAULT;
            }
            else switch (MaskParseState)
            {
                case MASK_PARSE_INIT:
                    if (isspace(incoming))
                        MaskParseState = MASK_PARSE_N;
                    else
                    {
                        MaskParseState = MASK_PARSE_BAD;
                        ErrorMessage = "Unknown mask command";
                    }
                    break;
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

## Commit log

2018-12-13 initial snapshot
    [ASW12V-Configurations.SLDASM, ASW12V-PCB.SLDASM, ASW12V-single.SLDASM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]
2018-12-14 documentation update
    [ASW12V.sch]
2018-12-20 work with more than one in the daisy chain
2018-12-20 widen more ground traces
2018-12-20 PCB as ordered
2019-01-02 gerber files for REV03 of the PCB
2019-07-15 support connectors as well as screw terminals
    [ASW12V-24.SLDASM, ASW12V-Configurations.SLDASM, ASW12V-PCB.SLDASM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]
2019-11-22 move loop to pin 2
2020-03-07 smd resistors on rev4 pcb
2020-03-07 rev05 pcb. change out darlington pnp for STA402
2020-03-22 docs and gerbers for rev 4 and rev 5
    [ASW12V.sch]
2020-03-23 remove stray trace on PCB REV5
2020-03-23 had-edit .top gerber to remove stray trace
2020-03-24 increase PCB clearances above PS2502 output pins
2020-04-01 increase enclosure PCB post diameters
    [ASW12V-24.SLDASM, ASW12V-single-connectors.SLDASM, ASW12V-single.SLDASM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]
2020-04-01 increase enclosure PCB post diameters and spacer for terminal block when used with STA402 PNP
    [ASW12V-24.SLDASM, ASW12V-single-connectors.SLDASM, ASW12V-single.SLDASM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]
2020-04-03 ws7i antennas
2020-04-11 make #4-40 holes a bit larger
    [ASW12V-24.SLDASM, ASW12V-single-connectors.SLDASM, ASW12V-single.SLDASM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]
2020-04-11 more build instructions
    [ASW12V-Jig-Clamp.SLDPRT, ASW12V-Jig-Clamp.STL, ASW12V-Jig-Latch.STL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]
2020-06-08 6 antennas at WS7I
2022-03-12 24 channel enclosure
    [ASW12V.cfg, Pcb-with-connectors.cfg, pcb-qtpy.step]
2022-03-13 more enclosure
    [ASW12V.cfg]
2022-03-18 rev07 gerbers
2022-03-26 0.1uF 1206 bypass
    [ASW12V.sch]
2022-03-29 remove old
    [ASW12V-24.SLDASM, ASW12V-Jig-Clamp.SLDPRT, ASW12V-Jig-Latch.sldprt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]
2022-03-29 convert to SSR and MAX7301
    [ASW12V-24.SLDASM, ASW12V-Jig-Clamp.SLDPRT, ASW12V-Jig-Clamp.STL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]
2023-05-06 output only
    [ASW12V-single.cfg]
2023-05-06 input and output
    [ASW12V-single.cfg]
